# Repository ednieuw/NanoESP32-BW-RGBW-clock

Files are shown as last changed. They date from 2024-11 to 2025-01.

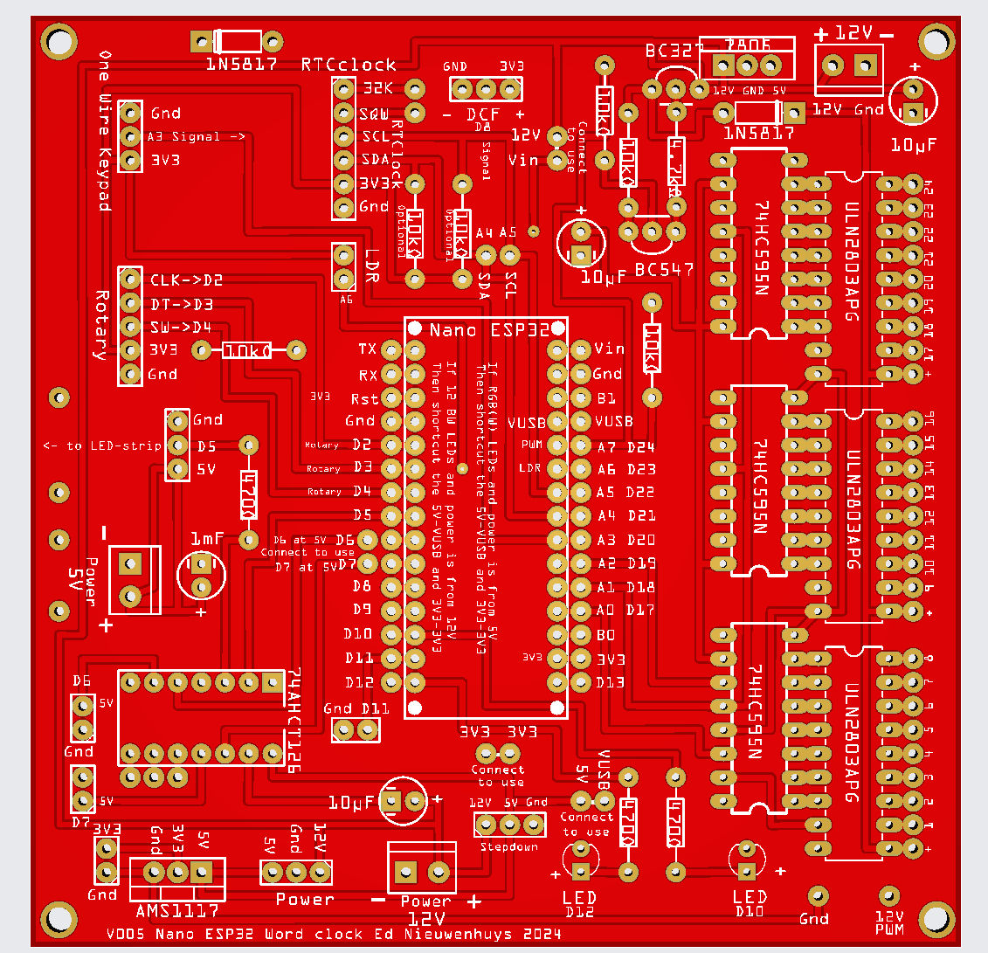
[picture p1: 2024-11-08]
V005UltimateArduinoPCBdesign/V005Ultimate Arduino Nano ESP32 PCB-2D.jpg

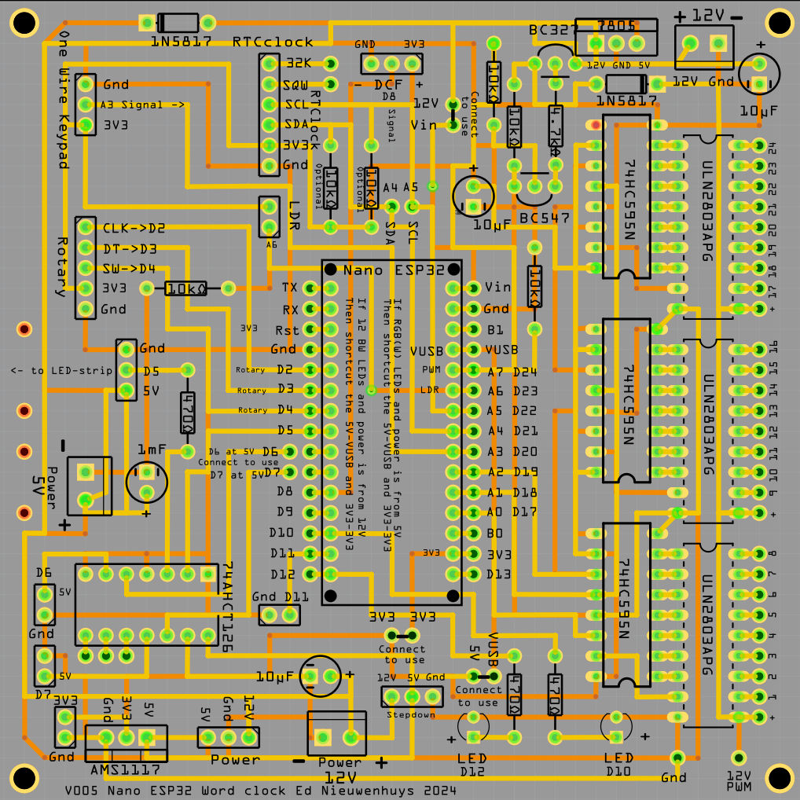
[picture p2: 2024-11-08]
V005UltimateArduinoPCBdesign/PCBUltimateV005.jpg

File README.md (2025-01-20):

# NanoESP32-BW-RGBW-clock

One PCB, one source code for 2835/3528 BW and SK6812/WS2812 RGB(W) LED-strips that can be used to built [word clocks](https://github.com/ednieuw/Arduino-ESP32-Nano-Wordclock) and Fibonacci clocks.
<br>
[Use the word clock selector page to compare other software/hardware designs to make.](https://github.com/ednieuw/WordclockSelector).<br>


The PCB with 24 white LEDs connected to the shift registers and a 16x16 RGB(W) LED matrix connected working simultaniously with the Nano ESP32

PCB-ESP32V002-3D

The [first word clock](https://ednieuw.home.xs4all.nl/Woordklok/Bouwpakket/WoordklokWitteLEDs.html) was [designed](https://github.com/ednieuw/Woordklok-witte-LEDs) with a ATMEGA328, combined with a rotary, DCF77 receiver, an accurate DS3231 RTC klok module and a Bluetooth module.
The electronic design was greatly simplified with the use of Arduino Nano Every and WS2812 RGB or SK6812 RGBW colour LEDs.

The arrival of the ESP32 was superior to the Arduino MCU's with WIFI and Bluetooth working both simultaneously. But with too many short living boards with different footprints, sizes and, often to less, pins a suitable satisfying design could not be made.

The Arduino Nano ESP32 with S3 processor was the promising Arduino product. 

Maintaining the source code for the White LED and RGB LED clocks was a time-consuming task. The white LED clock, which has been running in numerous clocks for over 10 years, has been built by many people and proved to be a very solid design wit LEDs operating for more than 10 years.

The RGB(W) clock made it possible to built a 4-language clock with 625 LEDs. The designs with one language in a 12 x 12 letter grid are much easier to built and the SK6812 RGBW LEDs can also give a pure white display and, if wished, also in any colour.

This is the ultimate fusion of all clocks; one PCB and one source code.<br> 
This board is mainly designed for the 12V white LED-strips with an Arduino Nano ESP32. Adding the RGB(W) functionality was minor and now with this PCB both LED types can be used. 
[A PCB for only RGB(W) LED-strips](https://github.com/ednieuw/NanoESP32PCB).

The several versions of this PCB design were kindly supported by [PCBWay](https://www.pcbway.com) that made the development of this PCB possible.<br>
The PCB was designed with Fritzing and the Gerber files uploaded to  the PCBWay web site.<br>
Delivery to The Netherlands was within a week. Just upload the [Gerber files from the ZIP file](https://github.com/ednieuw/NanoESP32PCB) to their site and pay the charges. Piece of cake.<br>
The boards looked perfect and soldering the components was easy.

In this [PDF](https://github.com/ednieuw/NanoESP32-BW-RGBW-clock/blob/main/NanoESP32-PCB.pdf) the solder instructions are documented.
SolderedUltimatePCB

[PCB in Action](https://github.com/user-attachments/assets/d6f986bc-7fbc-4ec3-888b-1f40599507ed) <br>
All LEDs functioning.

PCBUltimateV005

Download the latest V005 PCB Fritzing and gerber files from this page or [here](https://github.com/ednieuw/NanoESP32PCB)

# Manual
Use the manual of the RGBW ESP32 Nano Wordclock design here for the time being.
The software works ,almost, identical.
https://github.com/ednieuw/Arduino-ESP32-Nano-Wordclock

# Connections on the PCB.
The software support the following connected devices.

- A One-wire connection to pin A3.   See here [One wire 1x3 and 3x4 membrane keypad](https://ednieuw.home.xs4all.nl/Woordklok/OneWireKeyPad/OneWireKeyPad.html)
- A 6-pin connection to SDA and SCL pin A4 and A5 for a DS3231 RTC module. When no WIFI is available the software can use this very precise RTC module instead of the NTP time. The SDA and SCL line can be optionally pulled-up with two optional 10k resitors.The use of the DS3231 RTC module instead of WIFI/NTP can be switched on and off in the menu.
- A 3-pin connection  connected to D8 for a DCF-77 time module to get the time from a in Mainflingen (Germany) located time transmitter. [More here](https://ednieuw.home.xs4all.nl/Woordklok/DCF77_transceiver/DCFtransceiverklok.html). 
- A 5-pin connection for a rotary encoder. The use of the rotary encoder can be switcxhed on and off in the menu.
- A 3-pin connection to connect a SK6812 RGBW 0r WS2812 RGB LED strip
Fixed connection from pins A0, A1 and A2 to the three HC595 shift registers that turns on and off the ULN2803 IC's that switch on and off 12V 2835/3528 and many more white LED strips.
- A 2-pin connection from LDR to A6 to control the light intensity of the LEDs
- Pin A7 gives a PWM signal to the two transistors. The BC327 gives a 12V PWM signal to the white LEDs with a maximum of 800 mA. This is enough for a 50 cm large Word clock with 3 meters of 2835 LED-strip. (not all strips are on the same time) if more power is needed heavier transistors can be used or 24 relays can be turned on and off  
- A spare 2-pin connection to D11.
- A 3 pin connector connected via a 470 ohm resistor to Pin D5 through the level shifter is used to drive the RGB(W) LED-strip
- The 74AHCT125 level shifter shifts the data signals from pin D5, D6 and D7 from 3V3 to 5V. Pin D5 is used to control the RGB(W) LED-strip 
- Two 2-pin connectors for 5V signals from pin D6 and D7 through the level shifter.
- D10 and D12 connect to the right and left LED respectively.
- All pins can also be accessed from connection beside the Nano ESP32 connector.

An AMS1117 step down voltage regulator  can be fitted to have more power on the 3V3 pins instead of the 3V3 from the Arduino.
On top of the PCB a 78L05 voltage regulator can be used to convert 12V to 5 V to drive the 5V part of the PCB instead of a AMS1117 12V -> 5V voltage regulator.<br>
At the bottom an AMS1117 12V to 5V voltage regulator can be fitted instead of the 78L05 voltage regulator. What you like.

It is also possible to use the 5V of the ESP32 Nano when 12V is connected to Vin.
Altertively 5V can be drawn from the USB port when a USB-C cable is connected to the ESP32.
With jumpers on the PCB the different power options can be chosen.
At last a 5V - 12V power supply can be used and connected to the 5V-GND-12V connector at the bottom of the PCB instead of the voltage converters.<br> 
Do not use more than one of the three (AMS1117, 78L05 or 5/12V power supply) power options together.

For the white LED clock only a 12V connection to one of the two 12V power connectors is needed. Connect the 12V to Vin with a jumper.<br>
It is also possible to use a USB 5V to 12V cable. These are cheap and powerfull enough for the white LED clock. Even with a simple phone power supply. 

# For the colour clocks it is advisable to power the LED-strip separate from the PCB. Then do not connect the 5V to the LED-strip but only GND and the Data line on D5<br>
Up to 100 LEDs can be powered from the 5V power connector on the PCB. But keep in mind the current has to flow throught the PCB and those thin lines can melt if overloaded.<br> 
It is safer to feed the strip at several positions with 5V and connect at least one GND to the GND of the PCB.

# Components
In [PDF](https://github.com/ednieuw/NanoESP32-BW-RGBW-clock/blob/main/NanoESP32-PCB.pdf) the solder instructions are documented.
```

1 x PCB Nano ESP32
1 x Arduino Nano ESP32
1 x 1000 µF condensator 
3 x 10 µF capacitor
2 x diode 1N5817 (One on PCB version V002)
3 x 470Ω resistor
6 x 10kΩ resistor
1 x 4.7kΩ resistor
1 x BC327 transistor
1 x BC547 transistor
1 x LED red
1 x LED yellow
3 x 74HC595 DIP16 socket
3 x ULN2803APG  DIP18 socket
3 x 74HC595 8-bit shift register DIP16
3 x ULN2803APG voltage regulator DIP18
1 x 78L05/ L7805 voltage regulator 5V, 1.5A
1 x 74AHCT125 level shifter
1 x 74AHCT125 DIP14 socket
1 x cooling element voltage regulator
1 x 2-pin female connector (LDR)
1 x 3-pin female connector (DCF77)
1 x 5-pin female connector (Rotary)
1 x 6-pin female connector (DS3231 RTC)
2 x 15-pin female connector
1 x AMS1117 5V -> 3V3 Step-Down Regulator
1 x 12V -> 5V  voltage regulator module (78L05 or AMS 1117 12V -> 5V)
1 x USB cable 5V --> 12V DC
1 x pinheader 40 pins right-angled
1 x pinheader 6 pins straight with 3 x shortcut connectors
3 x 9-pin Dupont female connector
1 x KY-040 Keyes Rotary Encoder
1 x DCF77 DCF-2 module
1 x 4x3 or 1x3 membrane keypad
1 x RCT DS3231 Precisie klok module ZS-042
1 x CR 2032 3V lithium battery
1 x LDR light sensor 
1 x USB cable 5V --> 12V DC
1 x power connector 2.54mm
1 x power connector KF350 5.08 mm
1 x power connector XH2.54
1 x WS2812 LED-strip 
1 x SK6812 LED-strip 
1 x 2 meter Cool White SMD 2835/3528, 120 LEDS/meter, LED-strip 12V
```

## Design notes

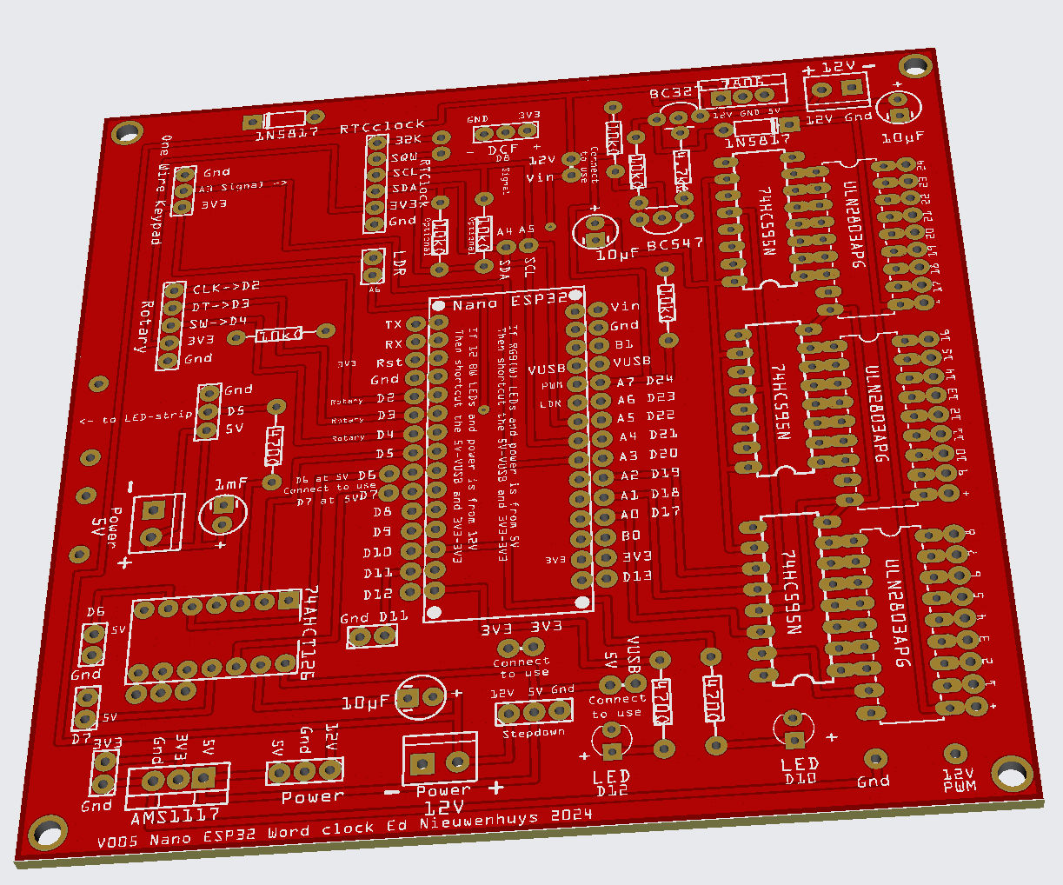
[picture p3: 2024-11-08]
V005UltimateArduinoPCBdesign/V005Ultimate Arduino Nano ESP32 PCB-3D.jpg

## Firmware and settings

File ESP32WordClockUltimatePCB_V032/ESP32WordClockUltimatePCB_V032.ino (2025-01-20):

/* 
 Author .    : Ed Nieuwenhuys
 Changes V001: Derived from ESP32Arduino_WordClockV035.ino
 Changes V002: SK6812 LEDs working. LDR pin A2 to A6
 Changes V003: HC595coding op pin A0 A1 A2 
 Changes V004: Time function upgraded. Removed RTCLib and added wire commands
 Changes V005: Moved BW and RGB clock defines to TABs
 Changes V006: No errors when compiling with UVBW, NLBW, NL114CLOCK
 Changes V007: No errors in FOURLANGUAGECLOCK
 Changes V008: Rotary, one-wire buttons and DCF77 added, RTC working, DCF77 NOT, One-wire working??
 Changes V009: Clean up. Optimized code and function name and location. 
               Rotary does not place the time in the DS3231   
               DCF77 does not function well with time functions. Try later
 Changes V010: When RGB clock is chosen HC595 shift one place every second. If RGB clock then it can be used to control something
 Changes V011: Clean up. 
 Changes V012: Added WIFI and NTP events. Added in Loop() NTPsyncEvent();
 Changes V013: Ulrich's clock face added #define NLM1M2M3M4L94 #define NLM1M2M3M4L256 and >18 to >19 in SayHour of Ulrich's clock.Clock faces identical as in ESP32ArduinoWordclockV036   
 Changes V014: Renamed to ESP32WordClockUltimatePCB-V014. All clock faces compile without errors
 Changes V015: Added   <meta name="google" content="notranslate" /> in Webpage.h
 Changes V016: Coding moved to relevant header files. Source compile for all clock selections        
 Changes V017: Reverted back to V015. The RGBW LED functions should remain in primary source code. M1M2M3M4 in BW clock. BWUV clock to Ulrich Vertessen for testing 
 Changes V018: Compiles with board esp32-> Arduino Nano ESP32 -> By GPIO number.  Added MIN0; to clear the four RGB(W) LEDs       
 Changes V019: Removed Colour display choice from menu with BW clocks
 Changes V020: Removed command WiFi.mode(WIFI_STA); 
 Changes V021: DS3231 use tested and status can be seen in menu. Corrected 2000 year mismatch in DS3231
 Changes V022: Changed PCB and ESP32 LEDs to analog control of the intensity
 Changes V024: Menu changed!! Rotary working again. Added void InitRotaryMod(void)
 Changes V025: CCC in menu to turn on/off BLE. Code synced with ESP32Arduino_WordClockV046 
 Changes V026: Added Rotary On/Off choice and scan WIFI network in menu. BLE delay(40) -> 10 Comparable with ESP32Arduino_WordClockV054 
 Changes V027: Fine tuned WIFIwasConnected. Removed NLM1M2M3M4L256. Comparable with ESP32Arduino_WordClockV055 
 Changes V028: Corrected when LEDs are turned on in EveryHour to force a minute update
               MDNS.begin(BLEbroadcastName). Option Q3 and Q4 were reversed and corrected
               Identical common routines ESP32ArduinoFibonacci_V003 / ESP32WordClockUltimatePCB_V028 / ESP32WordClockV056
 Changes V029: BBBB  Removed WhiteColour --> white.void Laatzien(int Delaymsec). Last used Color in digital display. WIFI custom name in router
               New design NLM1M2M3M4L94 --> NLM1M2M3M4L114
 Changes V030: NimBLE version 1.4.3 -> 2.1.2 upgrade:
                void onConnect(BLEServer* pServer) {deviceConnected = true; };
                void onDisconnect(BLEServer* pServer) {deviceConnected = false;}
                void onWrite(BLECharacteristic *pCharacteristic) 
                To:
                void onConnect(NimBLEServer* pServer, NimBLEConnInfo& connInfo) override {deviceConnected = true;Serial.println("Connected" ); };
                void onDisconnect(NimBLEServer* pServer, NimBLEConnInfo& connInfo, int reason) override {deviceConnected = false;Serial.println("NOT Connected" );}
                void onWrite(NimBLECharacteristic *pCharacteristic, NimBLEConnInfo& connInfo) override  
                added: pAdvertising->setName(BLEbroadcastName);   after pAdvertising->addServiceUUID(SERVICE_UUID);  
 Changes V031: Wire.begin(); // Keep Wire.begin close to the first I2C start to avoid WireTimeout()
               Comparable with ESP32Arduino_WordClockV069
 Changes V032: Added M1M2M3M4 in NL144. Comparable with ESP32Arduino_WordClockV070                
             
*** Special designed for ESP32 Ultimate PCB with shift registers and RGB(W) support *** 

How to compile: 

Check if #define ELEGANTOTA_USE_ASYNC_WEBSERVER 1 in ElegantOTA.h
Locate the ELEGANTOTA_USE_ASYNC_WEBSERVER macro in the ElegantOTA.h file, and set it to 1: -->  #define ELEGANTOTA_USE_ASYNC_WEBSERVER 1

Install Arduino Nano ESP32 boards
Board: Arduino Nano ESP32
Partition Scheme: With FAT
Pin Numbering: By GPIO number (legacy)

Select below, with ONLY ONE #define selected, the clock type
Upload the file to the Arduino Nano ESP32 installed on PCB "Nano ESP32 Word clock"

*/
// =============================================================================================================================
//--------------------------------------------
// ESP32 Definition of preferred word clock type
// Define the clock type by removing the // before the #define
//--------------------------------------------

// ------------------>   Define ONLY ONE clock type!

#define NL144CLOCK               // RGB(W) Standard 12x12 clock
//#define FOURLANGUAGECLOCK      // RGB(W) 4-languages clock
//#define NLM1M2M3M4L114         // NL clock with four extra LEDs for the minutes to light up for Ulrich
 
//#define NLBW                   // NL White LEDs clock with HC595 Shift bit registers for control
//#define UKBW                   // UK White LEDs clock with HC595 Shift bit registers for control
//#define UVBW                   // Ulrich White LEDs clock + M1M2M3M4 with HC595 Shift bit registers for control

//--------------------------------------------
// ESP32 Definition of installed modules
// Define the modules installed in the clock by removing the // before the #define
//--------------------------------------------
//#define ONEWIREKEYPAD3x1       // Use a 3x1 keypad with one wire
//#define ONEWIREKEYPAD3x4       // Use a 3x4 keypad with one wire

//#define DCF77MOD               // DCF77 installed. Does not work together with NTPtime!!. Remove NTP time functionality to use the DCF77

//--------------------------------------------
// ESP32 Includes defines and initialisations
//--------------------------------------------

#include <Preferences.h>
#include <RTClib.h>            // Used for connected DS3231 RTC // Reference https://adafruit.github.io/RTClib/html/class_r_t_c___d_s3231.html
                      #if ESP_ARDUINO_VERSION >= ESP_ARDUINO_VERSION_VAL(3, 0, 0)
#include "EdSoftLED.h"         // https://github.com/ednieuw/EdSoftLED for LED strip WS2812 or SK6812. Uses RMT driver
                      #else
#include <Adafruit_NeoPixel.h> // https://github.com/adafruit/Adafruit_NeoPixel  for LED strip WS2812 or SK6812
                      #endif
#include <NimBLEDevice.h>      // For BLE communication !!!Use NimBLE version 2.x.x https://github.com/h2zero/NimBLE-Arduino
#include <ESPNtpClient.h>      // https://github.com/gmag11/ESPNtpClient
#include <WiFi.h>              // Used for web page 
#include <AsyncTCP.h>          // Used for webpage  https://github.com/dvarrel/AsyncTCP                    old https://github.com/me-no-dev/ESPAsyncWebServer
#include <ESPAsyncWebServer.h> // Used for webpage  https://github.com/mathieucarbou/ESPAsyncWebServer     Old one with  https://github.com/me-no-dev/ESPAsyncWebServer
#include <ElegantOTA.h>        // If a large bunch of compile error see here :https://docs.elegantota.pro/async-mode
                               // Locate the ELEGANTOTA_USE_ASYNC_WEBSERVER macro in the ElegantOTA.h file, and set it to 1:
                               // #define ELEGANTOTA_USE_ASYNC_WEBSERVER 1
#include <ESPmDNS.h>           // To show BLEname in router
#include <DNSServer.h>         // For the web page to enter SSID and password of the WIFI router 
#include <Wire.h>              // Used for I2C 
#include <Encoder.h>           // For rotary encoder
#include <Keypad.h>            // For 3x1 membrane keypad instead of rotary encoder by Mark Stanley & Alexander Brevig 

                      #ifdef DCF77MOD
#include <DCF77.h>
#include <TimeLib.h>
                      #endif //DCF77MOD

                      #if defined(FOURLANGUAGECLOCK) || defined(NL144CLOCK) || defined( NLM1M2M3M4L94)
#define RGBCLOCK
                      #endif
                      #if defined(NLBW) || defined(UKBW)  || defined(UVBW)  
#define BWCLOCK
                      #endif
//--------------------------------------------
// SPIFFS storage
//--------------------------------------------
Preferences FLASHSTOR;

//--------------------------------------------
// COLOURS stored in Mem.DisplayChoice
//--------------------------------------------   
const byte DEFAULTCOLOUR = 0;
const byte HOURLYCOLOUR  = 1;          
const byte WHITECOLOR    = 2;
const byte OWNCOLOUR     = 3;
const byte OWNHETISCLR   = 4;
const byte WHEELCOLOR    = 5;
const byte DIGITAL       = 6;
const byte ANALOOG       = 7;

//------------------------------------------------------------------------------
// PIN Assigments for Arduino Nano ESP32
//------------------------------------------------------------------------------ 
 
enum DigitalPinAssignments {      // Digital hardware constants
 SERRX        = D0,               // D0 Connects to TX
 SERTX        = D1,               // D1 Connects to RX
 encoderPinB  = D2,               // D2 left (labeled CLK on decoder)no interrupt pin  
 encoderPinA  = D3,               // D3 right (labeled DT on decoder)on interrupt  pin
 clearButton  = D4,               // D4 switch (labeled SW on decoder)
 LED_PIN      = D5,               // D5 Pin to control colour SK6812/WS2812 LEDs
 PIN_D6       = D6,               // D6 To Level shifter 74AHCT125 when Connected
 PIN_D7       = D7,               // D7 To Level shifter 74AHCT125 when Connected
 DCF_PIN      = D8,               // D8 DCF pin
 DCF_LED_Pin  = D9,               // D9 Optional for DCF_LED 
 Empty        = D9,               // Empty on PCB ESP32 Word clock V003
 PCB_LED_D10  = D10,              // D10 Right LED on PCB ESP32 Word clock V003
 PIN_D11      = D11,              // D11 Connector on PCB
 PCB_LED_D12  = D12,              // D12 Left LEDon PCB ESP32 Word clock V003
 secondsPin   = D13,              // D13 GPIO48 Right LED on PCB V001 & V002 (#ifdef LED_BUILTIN  #undef LED_BUILTIN #define LED_BUILTIN 48 #endif)
 Nano_LED_D13 = D13               // D13 GPIO48 
 };
 
enum AnaloguePinAssignments {     // Analogue hardware constants ----
 LEDDataPin   = A0,               // HC595      D17
 LEDStrobePin = A1,               // HC595      D18
 LEDClockPin  = A2,               // HC595      D19
 OneWirePin   = A3,               // OneWirePin D20
 SDA_pin      = A4,               // SDA pin    D21
 SCL_pin      = A5,               // SCL pin    D22
 PhotoCellPin = A6,               // LDR pin    D23
 PWMpin       = A7                // Pin that controls PWM signal on BC327 transistor to dim light D24
};
//--------------------------------------------                                                //
const uint32_t black    = 0x000000, darkorange    = 0xFF8C00, red        = 0xFF0000, chartreuse   = 0x7FFF00;
const uint32_t brown    = 0x503000, cyberyellow   = 0xFFD300, orange     = 0xFF8000; 
const uint32_t yellow   = 0xFFFF00, cadmiumyellow = 0xFFF600, dyellow    = 0xFFAA00, chromeyellow = 0xFFA700;
const uint32_t green    = 0x00FF00, brightgreen   = 0x66FF00, apple      = 0x80FF00, grass        = 0x00FF80;  
const uint32_t amaranth = 0xE52B50, edamaranth    = 0xFF0050, amber      = 0xFF7E00;
const uint32_t marine   = 0x0080FF, darkviolet    = 0x800080, pink       = 0xFF0080, purple       = 0xFF00FF; 
const uint32_t blue     = 0x0000FF, cerulean      = 0x007BA7, sky        = 0x00FFFF, capri        = 0x00BFFF;
const uint32_t edviolet = 0X7500BC, frenchviolet  = 0X8806CE, coquelicot = 0xFF3800;
const uint32_t greenblue= 0x00F2A0, hotmagenta    = 0xFF00BF, dodgerblue = 0x0073FF, screamingreen= 0x70FF70;
      uint32_t white    = 0xFFFFFF, lgray         = 0x666666, wgray      = 0xAAAAAA;
      uint32_t gray     = 0x333333, dgray         = 0x222222;
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
void loop() 
{
 Loopcounter++;
 if (Demo)          Demomode();
 else               EverySecondCheck();                                                        // Let the second led tick and run the clock program                                                                        // For Over The Air updates This loop block is necessary for ElegantOTA to handle reboot after OTA update.
CheckDevices();
}
//--------------------------------------------                                                //
// COMMON Check connected input devices
//--------------------------------------------
void CheckDevices(void)
{
 CheckBLE();                                                                                  // Something with BLE to do?
 NTPsyncEvent();                                                                              // Check for NTP events
 SerialCheck();                                                                               // Check serial port every second 
 ElegantOTA.loop();                                                                           // For Over The Air updates This loop block is necessary for ElegantOTA to handle reboot after OTA update.
 if (Mem.UseRotary==1) RotaryEncoderCheck(); 
 if (Mem.UseRotary==2) Keypad3x1Check();
                                  #ifdef DCF77MOD
 if(UseDCF)  DCF77Check();
                                  #endif  //DCF77MOD                               
                                  #ifdef ONEWIREKEYPAD3x4   
 OnewireKeypad3x4Check(); 
                                  #endif  //ONEWIREKEYPAD3x4
                                  #ifdef ONEWIREKEYPAD3x1   
 OnewireKeypad3x1Check(); 
                                  #endif  //ONEWIREKEYPAD3x1
}
//--------------------------------------------                                                //
// COMMON Update routine done every second
//--------------------------------------------
void EverySecondCheck(void)
{
 static int Toggle = 0;
 uint32_t msLeap = millis() - msTick;                                                         // 
 if (msLeap >999)                                                                             // Every second enter the loop
 {
  msTick = millis();
  GetTijd(false);                                                                             // Get the time for the seconds 
  Toggle = 1-Toggle;                                                                           // Used to turn On or Off Leds
  UpdateStatusLEDs(Toggle);
                       #ifdef RGBCLOCK
  static uint8_t HC595value = 0;                                                              //                      
  HC595bank(HC595value);                                                                      // Option to run to LEDs on the shiftregisters every second
  if(++HC595value >= 24) HC595value = 0;                                                      // Let the HC595 shiftregister shift on one pin of the 24 
  SetSecondColour();                                                                          // Set the colour per second of 'IS' and 'WAS' 
                       #endif
  DimLeds(TestLDR);                                                                           // Every second an intensitiy check and update from LDR reading 
  if (timeinfo.tm_min != lastminute) EveryMinuteUpdate();                                     // Enter the every minute routine after one minute; 
  Loopcounter=0;
 }  
}

//--------------------------------------------                                                //
// COMMON Update routine done every minute
//-------------------------------------------- 
void EveryMinuteUpdate(void)
{   
 lastminute = timeinfo.tm_min; 
 if(Mem.WIFIOn && WIFIwasConnected)                                                                               // If WIFI switch is On.
   {
    if(WiFi.localIP()[0] == 0)
       {
        if(WIFIwasConnected)  WiFi.reconnect();                                                 // If connection lost and WIFI is used reconnect
        if(CheckforWIFINetwork(false) && !WIFIwasConnected) StartWIFI_NTP();                    // If there was no WIFI at start up start a WIFI connection  
        if(WiFi.localIP()[0] != 0) 
          {
          sprintf(sptext, "Reconnected to IP address: %d.%d.%d.%d", WiFi.localIP()[0], WiFi.localIP()[1], WiFi.localIP()[2], WiFi.localIP()[3] );
          Tekstprintln(sptext);
          }
        }
   } 
 GetTijd(false);
 Displaytime();                                                                               //PrintRTCTime();
 DimLeds(true);   
 if(timeinfo.tm_hour != lasthour) EveryHourUpdate();
}
//--------------------------------------------                                                //
// COMMON Update routine done every hour
//--------------------------------------------
void EveryHourUpdate(void)
{
 lasthour = timeinfo.tm_hour;
 //if (!Mem.StatusLEDOn) SetStatusLED(0,0,0);                                                // If for some reason the LEDs are ON and after a MCU restart turn them off.  
 if( (timeinfo.tm_hour == Mem.TurnOffLEDsAtHH) && (Mem.TurnOffLEDsAtHH != Mem.TurnOnLEDsAtHH))
       { LEDsAreOff = true;  ClearScreen(); }                                                 // Is it time to turn off the LEDs?
 if(timeinfo.tm_hour == Mem.TurnOnLEDsAtHH) 
   { 
    LEDsAreOff = false;
    lastminute = 99;                                                                          // Force a minute update
    Displaytime();  
   } 
 Mem.NVRAMmem[lasthour] =(byte)((SumLDRreadshour / NoofLDRreadshour?NoofLDRreadshour:1));     // Update the average LDR readings per hour
 SumLDRreadshour  = 0;
 NoofLDRreadshour = 0;
 if (timeinfo.tm_mday != lastday) EveryDayUpdate();  
}
//--------------------------------------------                                                //
// COMMON Update routine done every day
//--------------------------------------------
void EveryDayUpdate(void)
{
 if(timeinfo.tm_mday != lastday) 
   {
    lastday           = timeinfo.tm_mday; 
    Previous_LDR_read = ReadLDR();                                                            // to have a start value
    MinPhotocell      = Previous_LDR_read;                                                    // Stores minimum reading of photocell;
    MaxPhotocell      = Previous_LDR_read;                                                    // Stores maximum reading of photocell;
//    Mem.ReconnectWIFI = 0;                                                                    // Reset WIFI reconnection counter     
//    StoreStructInFlashMemory();                                                             // 
    }
}

//--------------------------------------------                                                //
// COMMON Update routine for the status LEDs
//-------------------------------------------- 
void UpdateStatusLEDs(int Toggle)
{
 if(Mem.StatusLEDOn)   
   {
    SetStatusLED((Toggle && WiFi.localIP()[0]==0) * 20, (Toggle && WiFi.localIP()[0]!=0) * 20 , (Toggle && deviceConnected) * 20); 
    SetPCBLED12( Toggle * 15);                                                                // links
    SetPCBLED10((1-Toggle) * 5);                                                              // rechts
    SetNanoLED13((1-Toggle) * 20);     
   }
   else
   {
    SetStatusLED(0, 0, 0); 
    SetPCBLED12(0);                                                                           //
    SetPCBLED10(0);                                                                           //
    SetNanoLED13(0);      
   }
}
//--------------------------------------------                                                //
// COMMON Control the RGB LEDs on the Nano ESP32
// Analog range 0 - 512. 0 is LED On max intensity
// 512 is LED off. Therefore the value is subtracted from 512 
//--------------------------------------------
void SetStatusLED(int Red, int Green, int Blue)
{
 analogWrite(LED_RED,   512 - Red);                                                                 // !Red (not Red) because 1 or HIGH is LED off
 analogWrite(LED_GREEN, 512 - Green);
 analogWrite(LED_BLUE,  512 - Blue);
}
//--------------------------------------------                                                //
// COMMON Control orange LED D13 on the Arduino 
//--------------------------------------------
void SetNanoLED13(int intensity) {analogWrite(secondsPin, intensity);}
//--------------------------------------------                                                //
// COMMON Control the RGB LED on the PCB
//--------------------------------------------
void SetPCBLED12(int intensity) {analogWrite(PCB_LED_D12, intensity);}
void SetPCBLED10(int intensity) {analogWrite(PCB_LED_D10, intensity);}
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

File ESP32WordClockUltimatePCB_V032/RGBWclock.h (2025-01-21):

//------------------------------------------------------------------------------FuncCRGBW
// RGBW LEDs Definition of installed language word clock
// These clocks have a 12 x 12 character matrix
//------------------------------------------------------------------------------

extern void Tekstprint(char const *tekst);
extern void Tekstprintln(char const *tekst);
extern void ColorLeds(char const *Tekst, int FirstLed, int LastLed, uint32_t RGBWColor);
extern void LedsOff(void);
extern void ShowLeds(void);
extern void CheckDevices(void);   
extern void TimePlaceDigit(byte uur, byte minuut);
extern uint32_t Wheel(byte WheelPos);
extern uint32_t FuncCRGBW( uint32_t Red, uint32_t Green, uint32_t Blue, uint32_t White);
void Laatzien(void);
void Laatzien(int Delaymsec); 
void SetColours(void);
void SetSecondColour(void);
void DisplayTime(void);
void Dutch(void);
void English(void);
void German(void);
void French(void);
void DitLeHeure(void);

extern struct tm timeinfo;                                             // Storage of time used in clock for time display

                     #ifdef FOURLANGUAGECLOCK
#define NL
#define UK
#define DE
#define FR    
                     #endif //FOURLANGUAGECLOCK  

//------------------------------------------------------------------------------
// RGBW LEDs Definition of LEDs to be used for minutes.
// Normally the number start at the end of the last LED used.
// In this case 139
// These LEDs can also be used in the white LED clock. 
//------------------------------------------------------------------------------
                       #ifdef RGBCLOCK
#define MIN0   ColorLeds("M0",    NUM_LEDS-4, NUM_LEDS-1, black); 
#define MIN1   ColorLeds("M1",    NUM_LEDS-4, NUM_LEDS-4, LetterColor); 
#define MIN2   ColorLeds("M2",    NUM_LEDS-3, NUM_LEDS-3, LetterColor); 
#define MIN3   ColorLeds("M3",    NUM_LEDS-2, NUM_LEDS-2, LetterColor);
#define MIN4   ColorLeds("M4",    NUM_LEDS-1, NUM_LEDS-1, LetterColor);                                           
                      #endif //RGBCLOCK                                      
//------------------------------------------------------------------------------
// RGBW LEDs Definition of LEDs to be used for the time.
// Changes these numberings to your design if needed
//------------------------------------------------------------------------------
                     #ifdef NL144CLOCK
const uint32_t NUM_LEDS  =  144 + 4;                             // How many leds in  strip? + 4 for the minutes
const byte MATRIX_WIDTH  =  12;                                  // Grid size For digital display mode.  
const byte MATRIX_HEIGHT =  12;                                  // Grid size For digital display mode.
// const uint32_t NUM_LEDS  =  256;                              // Temporary for 16x16LED WS2812. To clear all LEDs. During uploading LEDs get randomly On and Off
// const byte MATRIX_WIDTH  =  16;                                    // Grid size For digital display mode.
// const byte MATRIX_HEIGHT =  16;                                    // Grid size For digital display mode.

#define HET     ColorLeds("Het",     0,   2, MINColor);   
#define IS      ColorLeds("is",      4,   5, SECColor);  ColorLeds("", 8,10, 0); Is = true;
#define WAS     ColorLeds("was",     8,  10, SECColor);  ColorLeds("", 4, 5, 0); Is = false;
#define PRECIES ColorLeds("precies", 17, 23, LetterColor);
#define MTIEN   ColorLeds("tien",    12, 15, LetterColor); 
#define MVIJF   ColorLeds("vijf",    25, 28, LetterColor); 
#define KWART   ColorLeds("kwart",   30, 34, LetterColor);
#define VOOR    ColorLeds("voor",    44, 47, LetterColor);
#define OVER    ColorLeds("over",    38, 41, LetterColor);
#define HALF    ColorLeds("half",    48, 51, LetterColor);
#define MIDDER  ColorLeds("midder",  53, 58, LetterColor);
#define VIJF    ColorLeds("vijf",    66, 69, LetterColor);
#define TWEE    ColorLeds("twee",    60, 63, LetterColor);
#define EEN     ColorLeds("een",     72, 74, LetterColor);
#define VIER    ColorLeds("vier",    77, 80, LetterColor);
#define TIEN    ColorLeds("tien",    91, 94, LetterColor);
#define TWAALF  ColorLeds("twaalf",  84, 89, LetterColor);
#define DRIE    ColorLeds("drie",    96, 99, LetterColor);
#define NEGEN   ColorLeds("negen",  102,106, LetterColor);
#define ACHT    ColorLeds("acht",   114,117, LetterColor);
#define NACHT   ColorLeds("nacht",  114,118, LetterColor);
#define ZES     ColorLeds("zes",    110,112, LetterColor);
#define ZEVEN   ColorLeds("zeven",  121,125, LetterColor);
#define ELF     ColorLeds("elf",    128,130, LetterColor);
#define NOEN    ColorLeds("noen",   139,142, LetterColor);
#define UUR     ColorLeds("uur",    134,136, LetterColor);
#define EDSOFT  ColorLeds("EdSoft", 132,132, LetterColor);
#define MIN1    ColorLeds("M1",     110, 110, LetterColor); 
#define MIN2    ColorLeds("M2",     111, 111, LetterColor);                                   // MINColor); 
#define MIN3    ColorLeds("M3",     112, 112, LetterColor);
#define MIN4    ColorLeds("M4",     113, 113, LetterColor);  
#define X_OFF   ColorLeds("",         0,  2, 0);
#define X_ON    ColorLeds("",         0,  2, LetterColor);
#define NTPT    ColorLed( 96, orange);  ColorLed( 97, orange);  ColorLed( 98, orange);        // NTP
#define RTCT    ColorLed( 22, green);   ColorLed( 23, green);   ColorLed( 24, green);         // RTC
#define BLEONOFF ColorLed( 80, blue);   ColorLed( 81, blue);    ColorLed( 82, blue);          // BLE
                     #endif //NL144CLOCK


                     #ifdef NLM1M2M3M4L114
const uint32_t NUM_LEDS  =  114;                                    // How many leds in  strip? + 4 for the minutes
const byte MATRIX_WIDTH  =  11;                                    // NA Not used in this clock. 10 is fine 
const byte MATRIX_HEIGHT =  10;                                    // NA Not used in this clock. 10 is fine
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

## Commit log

2024-07-30 V004
    Changes V001: Derived from ESP32Arduino_WordClockV035.ino
    Changes V002: SK6812 LEDs working. LDR pin A2 to A6
    Changes V003: HC595coding op pin A0 A1 A2
    Changes V004: Time function upgraded. Removed RTCLib and added wire commands
2024-07-30 V002 PCB
2024-07-31 V006
    Changes V005: Moved BW and RGB clock defines to TABs
    Changes V006: No errors when compiling with UVBW, NLBW, NL114CLOCK
    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
    [BWclock.h, RGBWclock.h]
2024-08-01 V009
    A few bugs left but major functions are working
    [BWclock.h, RGBWclock.h]
2024-08-07 Nano ESP32 PCB V002
    [WoordklokV002.fzz]
2024-08-20 V017
    Changes V011: Clean up.
    Changes V012: Added WIFI and NTP events. Added in Loop() NTPsyncEvent();
    Changes V013: Ulrich's clock face added #define NLM1M2M3M4L94 #define NLM1M2M3M4L256 and >18 to >19 in SayHour of Ulrich's clock.Clock faces identical as in ESP32ArduinoWordclockV036
    Changes V014: Renamed to ESP32WordClockUltimatePCB-V014. All clock faces compile without errors
    Changes V015: Added <meta name="google" content="notranslate" /> in Webpage.h
    Changes V016: Coding moved to relevant header files. Source compile for all clock selections
    Changes V017: Reverted back to V015. The RGBW LED functions should remain in primary source code
    [BWclock.h, RGBWclock.h]
2024-09-05 V021 Three bin files included
    Changes V017: Reverted back to V015. The RGBW LED functions should remain in primary source code. M1M2M3M4 in BW clock. BWUV clock to Ulrich Vertessen for testing
    Changes V018: Compiles with board esp32-> Arduino Nano ESP32 -> By GPIO number. Added MIN0; to clear the four RGB(W) LEDs
    Changes V019: Removed Colour display choice from menu with BW clocks
    Changes V020: Removed command WiFi.mode(WIFI_STA);
    Changes V021: DS3231 use tested and status can be seen in menu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
    [BWclock.h, RGBWclock.h]
2024-10-07 ESP32 Woordklok Ultimate PCB V004
    [WoordklokV004.fzz]
2024-11-08 V005 Fritzing+Gerber files
    [WoordklokV005.fzz]
2025-01-20 V032
    Changes V028: Corrected when LEDs are turned on in EveryHour to force a minute update
    MDNS.begin(BLEbroadcastName). Option Q3 and Q4 were reversed and corrected
    Identical common routines ESP32ArduinoFibonacci_V003 / ESP32WordClockUltimatePCB_V028 / ESP32WordClockV056
    Changes V029: BBBB Removed WhiteColour --> white.void Laatzien(int Delaymsec). Last used Color in digital display. WIFI custom name in router
    New design NLM1M2M3M4L94 --> NLM1M2M3M4L114
    Changes V030: NimBLE version 1.4.3 -> 2.1.2 upgrade:
    Changes V031: Wire.begin(); // Keep Wire.begin close to the first I2C start to avoid WireTimeout()
    Comparable with ESP32Ard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
    [BWclock.h, ESP32WordClockUltimatePCB_V032.ino, RGBWclock.h]
2025-01-21 Corrected warning MIN0-MIN4 redefintion
    #define MIN0 ColorLeds("M0", NUM_LEDS-4, NUM_LEDS-1, black);
    #define MIN1 ColorLeds("M1", NUM_LEDS-4, NUM_LEDS-4, white);
    #define MIN2 ColorLeds("M2", NUM_LEDS-3, NUM_LEDS-3, white);
    #define MIN3 ColorLeds("M3", NUM_LEDS-2, NUM_LEDS-2, white);
    #define MIN4 ColorLeds("M4", NUM_LEDS-1, NUM_LEDS-1, white);
    [BWclock.h, RGBWclock.h]
